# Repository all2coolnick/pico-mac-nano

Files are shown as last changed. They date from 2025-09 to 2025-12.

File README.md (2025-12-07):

# pico-mac-nano

pico-mac-nano
pico-mac-nanobig brotherinside

v0.3 20 May 2025

Fork of https://github.com/evansm7/pico-mac v0.21

The purpose of this fork is the creation of a miniature functioning Macintosh running pico-mac on a [Waveshare Pico Zero](https://www.waveshare.com/wiki/RP2040-Zero) (or pin/function compatible RP2040 MCU) by adding support for output to a small TFT LCD panel. 

This involved the following steps:
   * Selecting and testing the smallest suitably high resolution display I could locate at
     a reasonable price.
   * Working backwards from the LCD image size to calculate scale of the Macintosh model.
   * Designing the internal layout of the Macintosh to accomodate all components.
   * 3D modelling the Macintosh case in two halves with internal supports for components
   * Designing a PCB to connect all components.
   * Updating the pico-mac source code to ...
   	 - configure the LCD via SPI interface shared with SD card module
   	 - output suitable 480x342 pixel frame buffer data for the LCD
   	 - use the Pico Zero's built in Neo-pixel RGB LED
   	 - output out of phase 600Hz square waves on two GPIOs for 1s at startup to simulate
   	  the Macintosh startup beep

The finished Macintosh is just 62mm high but houses a 2.0" TFT LCD panel, rp2040 Pico Zero MCU, micro-SD card reader and the custom PCB.

For more details on the journey and design decisions, see the [pico-mac-nano project page](https://blog.1bitrainbow.com/pico-mac-nano/).

## PCB files

The PCB folder contains all the gerber, drill hole, position and BOM files for the most recent revision of the PCB. These are as supplied to [JLC pcb]([https://blog.1bitrainbow.com/pico-mac-nano/](https://jlcpcb.com)). The format of BOM and position files may need to modified for other PCB manufacturers. JLC pcb can produce the bare board, the board with all SMC pre-fitted, or as we have, fully assembled with both SMC and through-hole components.

## 3D files

The 3D_model folder contains the .stl files for 3D printing the case, battery power module and box inserts (for a 75mm cube box). The case is comprised of the front housing, rear housing, switch blank (blocks the switch apperture intended for the [battery power module](https://www.1bitrainbow.com/parts-store.php?cPath=972_973_P4470)) and reset/boot select button actuator. The battery module comprises upper and lower halves and the rocker switch. The box folder contains the top and bottom insert files and the two halves of the accessory box.

## Firmware Files

The firmware folder contains pre-built .uf2 rp2040 firmware files for the Pico Zero. This includes version 3.2 built with the standard 128K RAM (this is the version used on all pre-assembled & kit form pico-mac-nanos shipped to date). Version 19 no longer uses my hacked Mac Plus ROM. Instead it adopts the newer pico-mac code to patch the ROM to the desired screen resolution based on the build parameters. It is also built with the 208K RAM option which allows it to run MacPaint, but only when booted from a disk image on a micro-SD card. This is because the disk image contained in the pico-mac-nano firmware is read-only anbd MacPaint requires a writeable disk.

## Disk Images

The disk_images folder contains writeable disk image files (.img) files for booting pico-mac-nano from a micro-SD card. Copy one of them to an ExFAT formatted micro-SD card (If you want to change the file name, make sure it still starts with "umac0") then with your pico-mac-nano powered down, insert the card into the slot on the rear (The card must be upside down due to the orientation of the SD board). When you power up, it should detect the SD card and the boot image, and boot from that instead of the built in disk image. This disk image is writeable so unlike the built in disk image, any changes made to the contents of the disk while booted from it will remain. This is good in that you can save files you worked on, plus some applications like MacPaint require a writeable boot disk to run, but it also means it can become corrupted during a system crash.

The version 1 file is a 10MB .img version of the built in .dsk disk image used in all pico-mac-nanos shipped to date. Subsequent versions add more applications, utilities and games which have been found to broadly work within pico-mac.

## Other folders

Data sheets for the TFT module and the controller are in the data_sheets directory.

The external, include and src folders contain the pico-mac-nano branch of the pico-mac source code, and are only needed if you plan to compile and build the firmware yourself.

All the indivudial parts used in pico-mac-nano, or a full self-assemble kit are available on [1bitrainbow.com](https://www.1bitrainbow.com/parts-store.php?cPath=972_973). This includes the 3D printed case, the fully assembled custom PCB and the Pico Zero (pre-flashed with the latest pico-mac-nano firmware). 

## Hardware Notes

The pico code, PCB and Macintosh case are all designed for the 2.0" 480x640px DX7 D200N2409V0 LCD panel. This uses the ST7701S controller, is configured via SPI and receives image data in RGB565 (16-bit colour). This LCD is natively portrait and the ST7701S controller does not offer image rotation in hardware so I am displaying a 480x342 image across the upper half of the LCD panel. See the [pico-mac-nano project page](https://blog.1bitrainbow.com/pico-mac-nano/) for more details of how I got to this decision.

The case and internal layout is designed to allow the Pico Zero and SD module to be connected via 2.54mm header sockets rather than being soldered. Due to the small size of the PCB, I chose not to include sockets for the unused Pico Zero pins. Not having these unnecessary through-hole pins allowed routing of traces more efficiently. Consequently, the Pico Zero connects to the PCB via a 9-pin (J3), a 2-pin (J4), and a 4-pin (J6) socket.

The PCB includes the capacitors (C1 & C2) recommended by evansm7 across the micro-SD card module power rails.

The Pico 5V (VCC) is used to power the TFT backlight via a resistor (R1) which maintains the correct forward voltage specified by the TFT data sheet.

The 40-pin, vertical FFC socket (J1) is used to connect the TFT LCD panel. Note that for some reason, the LCD flex cable has its 'pin' numbers labelled in the reverse order to the FCC socket. This is why the PCB indicates where the LCD flex pin 1 should be.

Labelled test pads are provided on the PCB for all data signals.

Provision for battery power is provided on the PCB in the form of +5v and Ground header pins. This 5v input passes through an on-board Schottky diode (D1) to protect against pico-mac-nano being connected to a USB host and receiving 5V via USB while using battery power.

All components should be mounted on the underside of the PCB with the exception of the 2-pin 2.54mm male header (right-angle if using the [1-bit rainbow battery power module](https://www.1bitrainbow.com/parts-store.php?cPath=972_973_P4470)) for 5v battery power, and the 2-pin 2.54mm female header for Audio (Beep). These should be mounted on the top to allow connection of a power source and/or speaker.

pcb bottom
pcb top side

For reference, here are the pin assignments I have used for the Pico Zero.

|**Pin**|Ref|**Function**|
| --- | --- | --- |
|1		|5V			|VCC (TFT Backlight)|
|2		|GND		|Ground|
|3		|3V3		|VDD|
|4		|GPIO 29	|H-Sync|
|5		|GPIO 28	|Pix Clk|
|6		|GPIO 27	|V-Sync|
|7		|GPIO 26	|Vid Data|
|8		|GPIO 15	|TFT Reset|
|9		|GPIO 14	|TFT SPI CS|
|10		|GPIO 13	|Audio +|
|11		|GPIO 12	|Audio -|
|12		|GPIO 11	|N/C|
|13		|GPIO 10	|N/C|
|14		|GPIO 9		|N/C|
|15		|GPIO 8		|N/C|
|16		|GPIO 7		|N/C|
|17		|GPIO 6		|N/C|
|18		|GPIO 5		|SD SPI CS|
|19		|GPIO 4		|SPI MISO (shared)|
|20		|GPIO 3		|SPI MOSI (shared)|
|21		|GPIO 2		|SPI Clk (shared)|
|22		|GPIO 1		|N/C|
|23		|GPIO 0		|N/C|

The Audio + and Audio - pins output a 600Hz square wave for 1 second at the start of the initialisation code to give an approximate rendition of the original Macintosh startup beep. Audio - is just the inverse of (180 deg out of sync with) Audio +. By connecting a speaker between this pair of outputs, we get a 6.6v differential signal which gave an acceptable volume without the need for any amplification. When the speaker was just connected between one output and ground, the volume was too low to be of use (In case you're worrying, both pins are set low after the beep so the Pico is not left with a high GPIO shorting to ground through the speaker).
Audio + and Audio - are presented on their own header pins on the PCB to allow a speaker to be easily connected.
Using a suitable inductor (the value will depend on the impedance of the speaker you are using) in series with the speaker, or a capacitor across the speaker, should filter out some of the higher frequencies so the beep is less buzzy but I found that this significantly reduced the overall volume so our [speaker module](https://www.1bitrainbow.com/parts-store.php?cPath=972_973_P4489) does not include such a low pass filter.

## Battery Power Module

The optional battery power module uses a 3v, non-rechargeable, lithium CR2 battery. As well as the 3D printed chassis and rocker switch, it incorporates a tiny 2A 5v step up module, a micro switch, a 2-pin female 2.54mm header socket, battery contacts and four interconnecting wires. If you want to build it yourself, a full kit is available on [1bitrainbow.com](https://www.1bitrainbow.com/parts-store.php?cPath=972_973). There is an assembly video guide on our [YouTube channel](https://www.youtube.com/@1BitRainbow). Ready made units are also available on [1bitrainbow.com](https://www.1bitrainbow.com/parts-store.php?cPath=972_973_P4470).
I suggest 3D printing the upper and lower battery module parts using PLA+ or PETG so it is stronger than if you printed in standard PLA.

## Box

I originally offered the pre-assembled pico-mac-nano in a collectors edition which came in a replica of the original 'picasso' box complete with an accessory case and flexible top & bottom inserts. At Apple's request, we have stopped offering these but if you would like to make your own box, the .stl files to 3D print the inserts and accessory box and in the 3D_model folder. These are designed for a 75mm cube corrugated cardboard box. We used white TPU 95A filament for the inserts and white PLA for the accessory box. TPU can be tricky to print with and I found that we had to dry in a filament dryer for 12h before use and we kept it in the dryer while printing, feeding via ptfe tube all the way to the extruder. I tried many different TPU brands but found Overture to be the most reliable on our Bambu Lab A1 printers. We used eSun basic white PLA for the accessory box which is a nice warm, solid white.
Box kits including the inserts and accessory box are available on [1bitrainbow.com](https://www.1bitrainbow.com/parts-store.php?cPath=972_973).

## Disclaimer
As with the pico-mac project, pico-mac-nano is a personal hobby project and proof of concept rather than a commercial product. My aim was to see how small I could make it and this involved some compromises. This project is provided with no warranty and has not been tested against any recognised safety standard. All due care has been taken in design/docs, but if you choose to build it then I disclaim any responsibility for your hardware or personal safety.

Below is a modified version of [evansm7](https://github.com/evansm7) original readme from pico-mac v0.21 minus the Hardware Construction section since this variant uses a custom PCB so there is none of the original construction to be done.

# Pico Micro Mac (pico-umac) v0.2
This project embeds the [umac Mac 128K
emulator](https://github.com/evansm7/umac) project into a Raspberry Pi
Pico microcontroller.  At long last, the worst Macintosh in a cheap,
portable form factor!

It has features, many features, the best features:

   * Outputs 480x342px at 60Hz, monochrome to 2.0" LCD 
   * USB HID keyboard and mouse
   * Read-only disc image in flash (your creations are ephemeral, like life itself)
   * Or, if you have a hard time letting go, support for rewritable
     disc storage on an SPI-attached SD card
   * Mac 128K by default, or you can make use of more of the Pico's
     memory and run as a _Mac 208K_

Great features.  It even doesn't hang at random!  (Anymore.)

The _Mac 208K_ was, of course, never a real machine.  But, _umac_
supports odd-sized memories, and more memory runs more things.  A
surprising amount of software runs on the 128K config, but if you need
to run _MacPaint_ specifically then you'll need to build both SD
storage in addition to the _Mac 208K_ config.

To build this project yourself, you'll need at least a WaveShare Pico Zero or compatible board, a 3D printer, the 2.0" LCD panel, SPI micro-SD card module, interconnect PCB, USB mouse (and maybe a USB keyboard/hub), plus a suitable OTG USB splitter.

# Build

## Prerequisites/essentials

   * git submodules
      - Clone the repo with `--recursive`, or `git submodule update --init --recursive`
   * Install/set up the [Pico/RP2040 SDK](https://github.com/raspberrypi/pico-sdk)

## Build umac

Install and build `umac` first using the display width and height options. 
It'll give you a preview of the fun to come, plus is required to generate a patched ROM image.

```
cd external/umac
make DISP_WIDTH=480 DISP_HEIGHT=342
```

If you want to use a non-default memory size (i.e. >128K) you will
need to build `umac` with a matching `MEMSIZE` build parameter, for
example:

```
cd external/umac
make DISP_WIDTH=480 DISP_HEIGHT=342 MEMSIZE=208
```

This is because `umac` is used to patch the ROM, and when using
unsupported sizes between 128K and 512K the RAM size can't be probed
automatically, so the size needs to be embedded.

## Build pico-umac

Do the initial Pico SDK `cmake` setup into an out-of-tree build dir,
providing config options if required.

From the top-level `pico-umac` directory:

```
mkdir build
(cd build ; PICO_SDK_PATH=/path/to/sdk cmake .. <options>)
```

If you want more than the default 128K of memory, you need to build with the following option.
 
   * `-DMEMSIZE=<size in KB>`: The maximum practical size is about
     208KB, but values between 128 and 208 should work on a RP2040.
     Note that although apps and Mac OS seem to gracefully detect free
     memory, these products never existed and some apps might behave
     strangely.
      - With the `Mac Plus` ROM, a _Mac 128K_ doesn't quite have
        enough memory to run _MacPaint_.  So, 192 or 208 (and a
        writeable boot volume on SD) will allow _MacPaint_ to run.
      - **NOTE**: When this option is used, the ROM image must be
          built with an `umac` build with a corresponding `MEMSIZE`

**NOTE** All other options available in pico-mac are still recognised but are not listed here because the LCD and custom PCB used in pico-mac-nano require them to be set to specific values. Overriding the default for any option other than DMEMSIZE will cause problems.

Tip: `cmake` caches these variables, so if you see weird behaviour
having built previously and then changed an option, delete the `build`
directory and start again.

## ROM image

The flow is to use `umac` built on your workstation (e.g. Linux,
but WSL may work too) to prepare a patched ROM image.

`umac` is passed the 4D1F8172 MacPlusv3 ROM, and `-W` to write the
post-patching binary out:

```
./external/umac/main -r '4D1F8172 - MacPlus v3.ROM' -W rom.bin
```

Note: Again, remember that if you are using the `-DMEMSIZE` option to
increase the `pico-umac` memory, you will need to create this ROM
image with a `umac` built with the corresponding `MEMSIZE` option, as
above.

## Disc image

Micro-SD support is enabled by default. An internal read-only disc image is
still stored in flash by default which is used as a fallback if
no SD card is present, no valid boot image exists on the SD card, or the SD boot fails.

Grab a Macintosh system disc from somewhere.  A 400K or 800K floppy
image works just fine, up to System 3.2 (the last version to support
Mac128Ks).  I've used images from
<https://winworldpc.com/product/mac-os-0-6/system-3x> but also check
the various forums and MacintoshRepository.  See the `umac` README for
info on formats (it needs to be raw data without header).

The image size can be whatever you have space for in flash (typically
about 1.3MB is free there), or on the SD card.  (I don't know what the
HFS limits are.  But if you make a 50MB disc you're unlikely to fill
it with software that actually works on the _Mac 128K_ :) )

Use a FAT-formatted micro-SD card and copy your disc image
into _one_ of the following files in the root of the card:

   * `umac0.img`:  A normal read/write disc image
   * `umac0ro.img`:  A read-only disc image

## Putting it together, and building

Given the `rom.bin` prepared above and a `disc.bin` destinated for
flash, you can now generate includes from them and perform the build:

```
mkdir incbin
xxd -i < rom.bin > incbin/umac-rom.h
xxd -i < disc.bin > incbin/umac-disc.h
make -C build
```

You'll get a `build/firmware.uf2` out the other end.  Flash this to
your Pico Zero: e.g. plug it into your computer with the Boot Select button held down. This should cause the Pico Zero to appear as a removable volume. Drag and drop the formware file onto the volume. ([evansm7](https://github.com/evansm7) advocated using an SWD probe but due to design constraints, UART serial pins are not routed on the custom PCB)

The RGB LED should light up blue while the audio beep is being played, rapidly flash red while the LCD is being configured and then steadily flash green at about 2Hz.

# Software

Both CPU cores are used, and are overclocked (blush) to 250MHz so that
Missile Command is enjoyable to play.

The `umac` emulator and video output runs on core 1, and core 0 deals
with USB HID input.  Video DMA is initialised pointing to the
framebuffer in the Mac's RAM.

Other than that, it's just a main loop in `main.c` shuffling things
into `umac`.

Quite a lot of optimisation has been done in `umac` and `Musashi` to
get performance up on Cortex-M0+ and the RP2040, like careful location
of certain routines in RAM, ensuring inlining/constants can be
foldeed, etc.  It's 5x faster than it was at the beginning.

The top-level project might be a useful framework for other emulators,
or other projects that need USB HID input and a framebuffer (e.g. a
VT220 emulator!).

The USB HID code is largely stolen from the TinyUSB example, but shows
how in practice you might capture keypresses/deal with mouse events.

## Video

The video system is pretty good and IMHO worth stealing for other
projects: It uses one PIO state machine and 3 DMA channels to provide
a rock-solid bitmapped 1BPP 480x342 video output. ~~The Mac 512x342
framebuffer is centred inside this by using horizontal blanking
regions (programmed into the line scan-out) and vertical blanking
areas from a dummy "always black" mini-framebuffer.~~

~~It supports (at build time) flexible resolutions/timings.  The one
caveat (or advantage?) is that it uses an HSYNC IRQ routine to
recalculate the next DMA buffer pointer; doing this at scan-time costs
about 1% of the CPU time (on core 1).  However, it could be used to
generate video on-the-fly from characters/tiles without a true
framebuffer.~~

I'm considering improvements to the video system:

   * Supporting multiple BPP/colour output
   * Implement the rest of `DE`/display valid strobe support, making
     driving LCDs possible.
   * Using a video DMA address list and another DMA channel to reduce
     the IRQ frequency (CPU overhead) to per-frame, at the cost of a
     couple of KB of RAM.

# Licence

`hid.c` and `tusb_config.h` are based on code from the TinyUSB
project, which is Copyright (c) 2019, 2021 Ha Thach (tinyusb.org) and
released under the MIT licence.  `sd_hw_config.c` is based on code
from the no-OS-FatFS-SD-SPI-RPi-Pico project, which is Copyright (c)
2021 Carl John Kugler III.

The remainder of the code is released under the MIT licence:

 Copyright (c) 2024 Matt Evans:

 Permission is hereby granted, free of charge, to any person obtaining a copy
 of this software and associated documentation files (the "Software"), to deal
 in the Software without restriction, including without limitation the rights
 to use, copy, modify, merge, publish, distribute, sublicense, and/or sell
 copies of the Software, and to permit persons to whom the Software is
 furnished to do so, subject to the following conditions:

 The above copyright notice and this permission notice shall be included in all
 copies or substantial portions of the Software.

 THE SOFTWARE IS PROVIDED "AS IS", WITHOUT WARRANTY OF ANY KIND, EXPRESS OR
 IMPLIED, INCLUDING BUT NOT LIMITED TO THE WARRANTIES OF MERCHANTABILITY,
 FITNESS FOR A PARTICULAR PURPOSE AND NONINFRINGEMENT. IN NO EVENT SHALL THE
 AUTHORS OR COPYRIGHT HOLDERS BE LIABLE FOR ANY CLAIM, DAMAGES OR OTHER
 LIABILITY, WHETHER IN AN ACTION OF CONTRACT, TORT OR OTHERWISE, ARISING FROM,
 OUT OF OR IN CONNECTION WITH THE SOFTWARE OR THE USE OR OTHER DEALINGS IN THE
 SOFTWARE.

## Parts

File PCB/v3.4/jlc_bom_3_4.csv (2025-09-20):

Comment | Designator | Footprint | JLCPCB Part #
1uf Tantalum 16v | C1 | SMD 1206 (3216 metric) | C7171
0.1uf MLCC 50v | C2 | SMD 1206 (3216 metric) | C24497
Schottky Diode 40v 1A | D1 | SMD SOD-123 | C8598
FFC2A32-40-T | J1 | SMD 0.5-40PVertical welding | C11080
22ohms 250mW | R1 | SMD 1206 (3216 metric) | C17958
6-pole Female Vertical Header | J2 | 2.54mm pitch through hole | C40877
9-pole Female Vertical Header | J3 | 2.54mm pitch through hole | C22438159
2-pole Female Vertical Header | J4 | 2.54mm pitch through hole | C49661
4-pole Female Vertical Header | J6 | 2.54mm pitch through hole | C2685089
2-pole Female Vertical Header | J7 | 2.54mm pitch through hole | C49661
2-pole Male 90º Bend Header | J9 | 2.54mm pitch through hole | C5383119

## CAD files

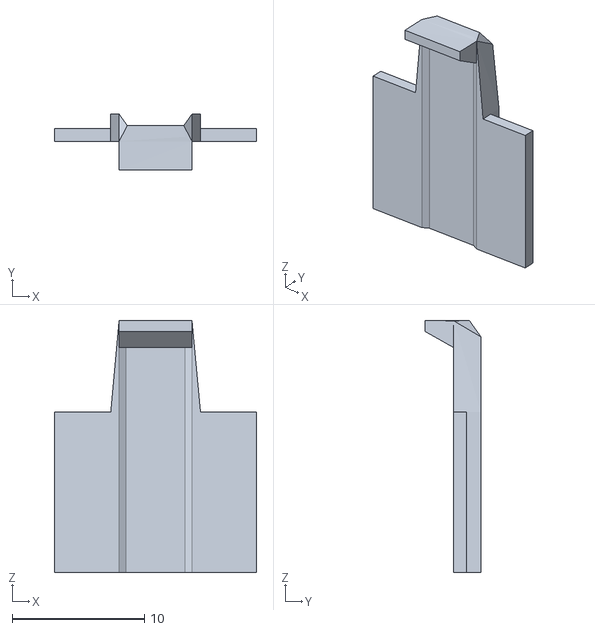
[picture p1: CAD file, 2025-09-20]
3D_model/battery module/bm_clip_v1.stl
15.3 x 4.24 x 19.1

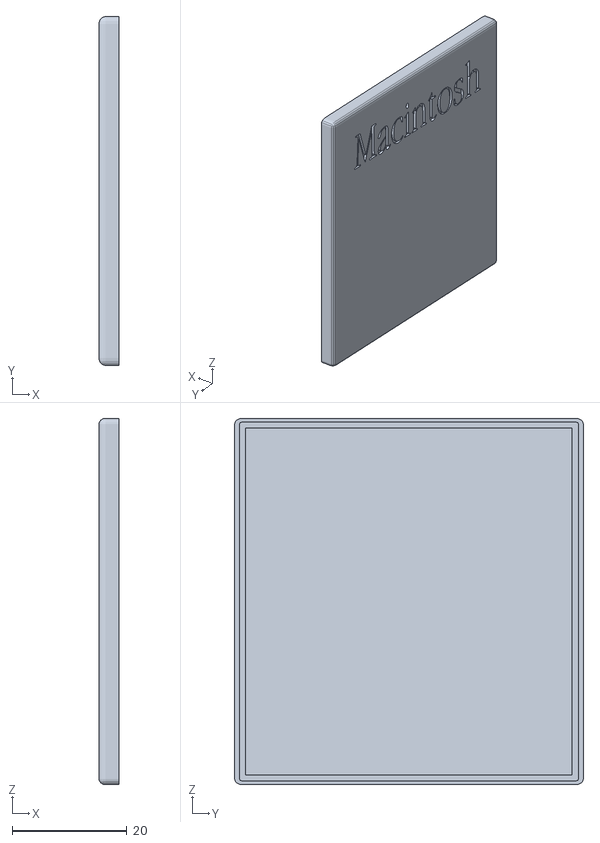
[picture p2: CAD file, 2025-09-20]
3D_model/box parts/acc_box_lid_v4.stl
3.53 x 60.8 x 63.8

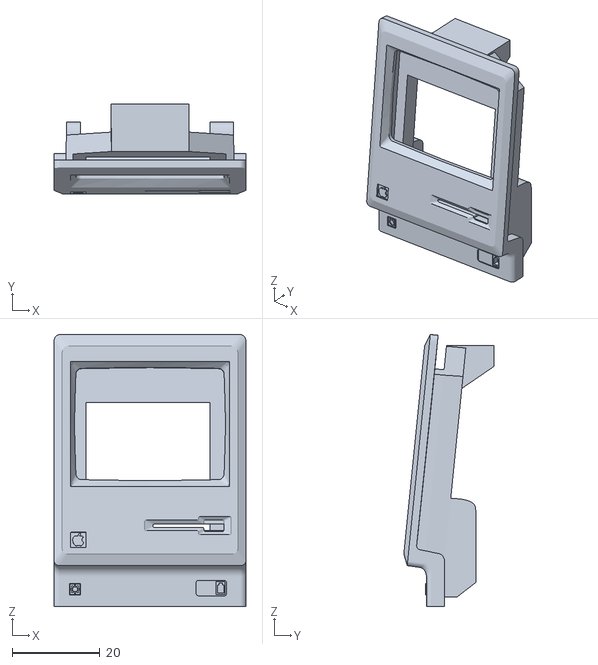
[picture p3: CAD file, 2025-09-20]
3D_model/pico-mac-nano case/pmn_front_case_v4.stl
43.8 x 20.6 x 62.0

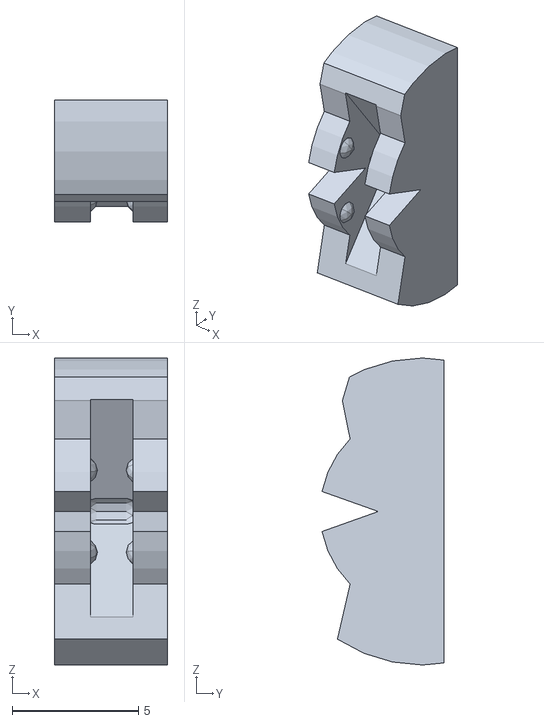
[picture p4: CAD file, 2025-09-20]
3D_model/battery module/bm_rocker_v5.stl
4.48 x 4.83 x 12.2

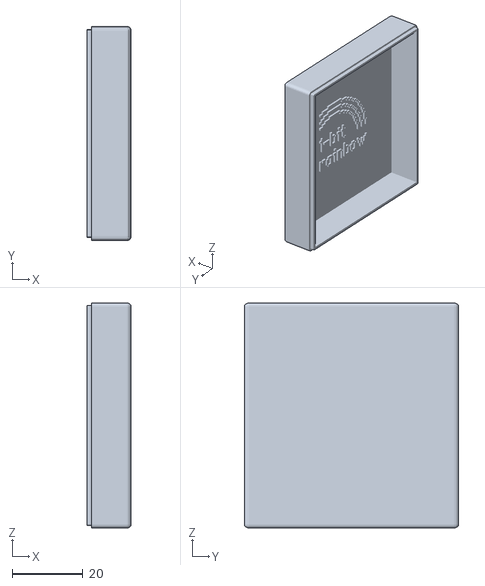
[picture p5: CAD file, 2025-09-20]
3D_model/box parts/acc_box_bottom_v2.stl
12.6 x 60.8 x 63.8

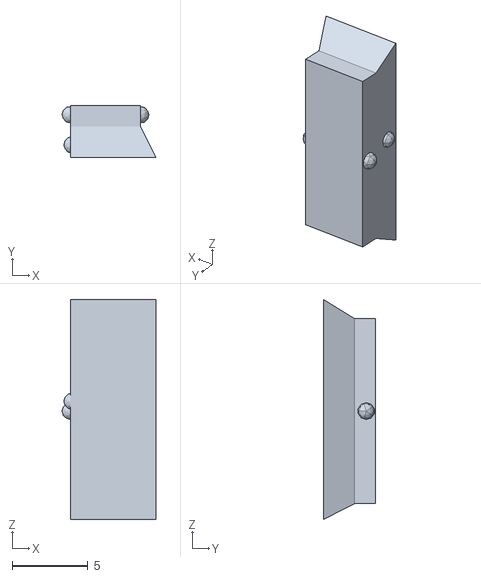
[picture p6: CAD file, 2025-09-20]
3D_model/pico-mac-nano case/pmn_switch_blank_v4.stl
6.22 x 3.44 x 14.5

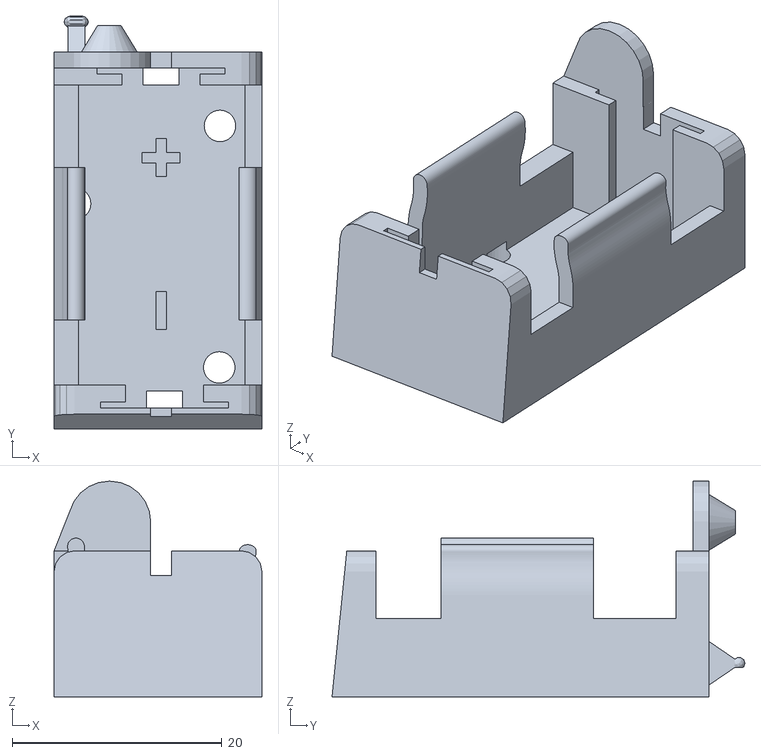
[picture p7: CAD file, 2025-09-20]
3D_model/battery module/bm_upper_v4.stl
19.8 x 39.3 x 20.5

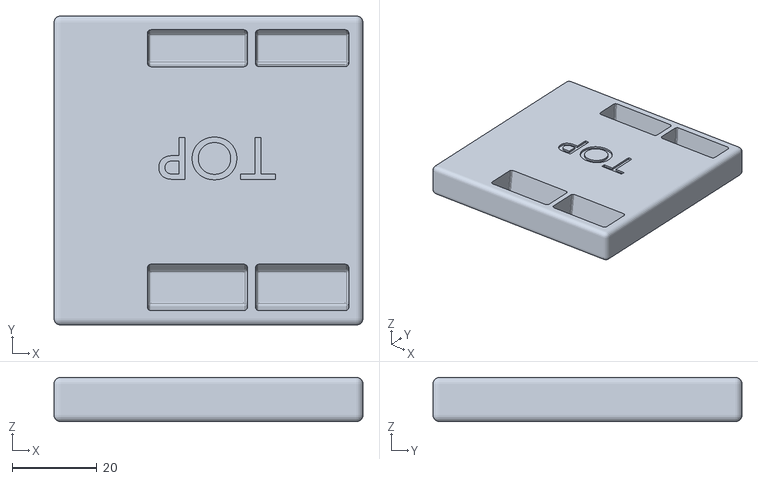
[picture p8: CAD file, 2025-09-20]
3D_model/box parts/box_insert_top_v12.stl
73.0 x 73.0 x 10.4

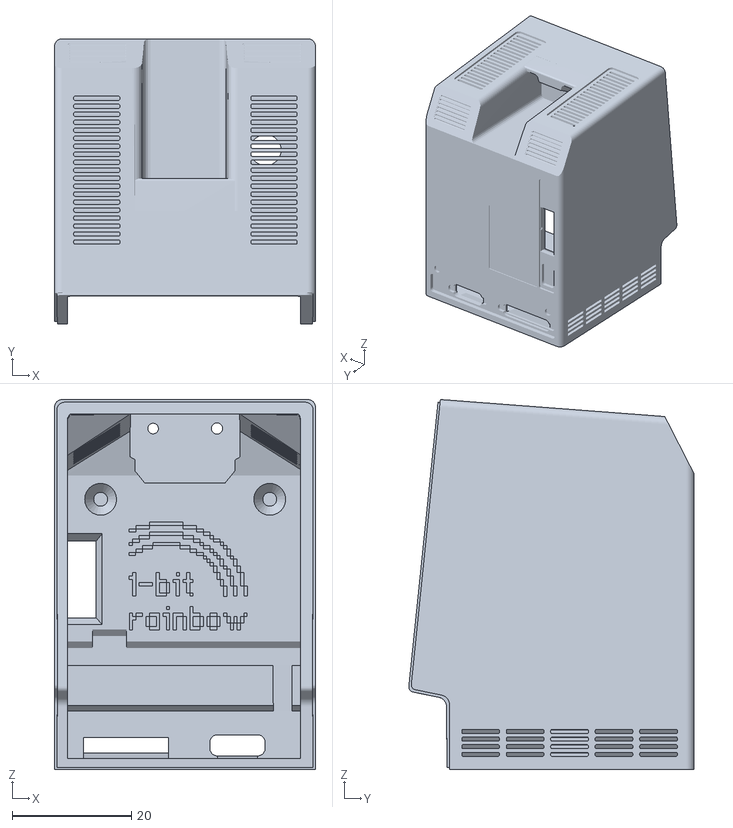
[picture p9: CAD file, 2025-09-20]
3D_model/pico-mac-nano case/pmn_rear_case_v14.stl
43.8 x 47.9 x 62.1

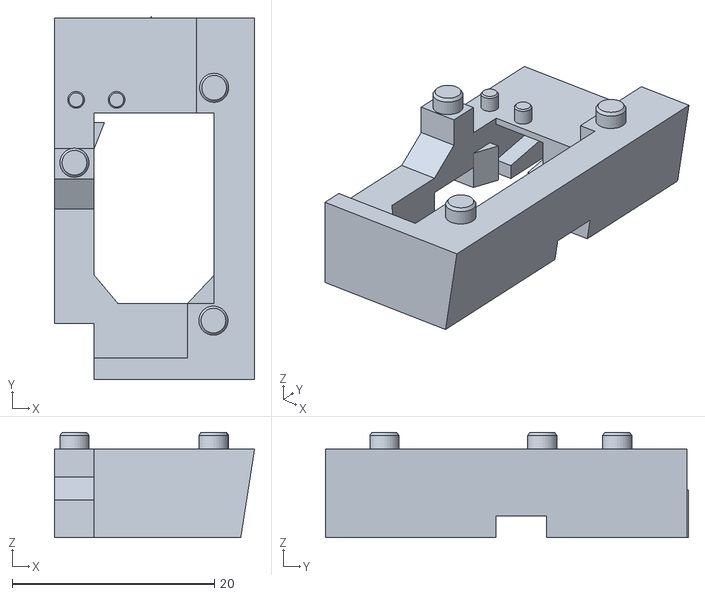
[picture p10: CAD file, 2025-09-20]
3D_model/battery module/bm_lower_v8.stl
19.8 x 35.9 x 10.4

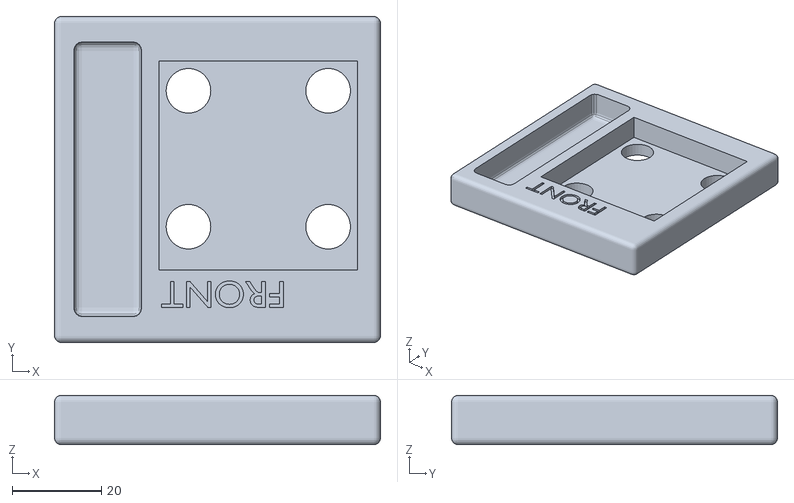
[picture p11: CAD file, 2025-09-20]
3D_model/box parts/box_insert_bottom_v12.stl
73.0 x 73.0 x 11.0

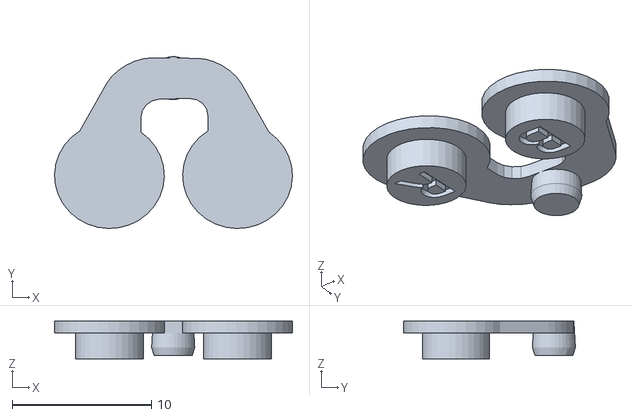
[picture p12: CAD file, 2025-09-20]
3D_model/pico-mac-nano case/pmn_reset_button_v4.stl
17.1 x 12.4 x 2.70

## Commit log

2025-09-20 Added 3D models for battery module and box inserts. Updated rear case 3D model
    [KiCAD_uPicomac3_4-B_Courtyard.gbr, KiCAD_uPicomac3_4-B_Cu.gbr, KiCAD_uPicomac3_4-B_Fab.gbr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]
2025-09-20 Update README.md
    Included notes on battery module
2025-09-20 Added accessory box 3D files
    [acc_box_bottom_v2.stl, acc_box_lid_v4.stl, box_insert_bottom_v12.stl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]
2025-12-07 Added disk images and v19 firmware
    New disk_images folder containing .img files that can be placed on an ExFAT formatted micro-sd card use used to boot pico-mac-nano.
    Added pico-mac-nano pre-built firmware version 19 which no longer relies on my hacked Mac Plus ROM. Code merged from pico-mac to allow ROM to be patched to desired screen resolution. It is also built with the 208K memory option.
2025-12-07 Clarify source code folder usage in README
    Added information about the pico-mac source code folders for firmware compilation.
2025-12-07 Fix typos and enhance clarity in README
    Updated descriptions for the battery power module and box sections, correcting typos and improving clarity.
